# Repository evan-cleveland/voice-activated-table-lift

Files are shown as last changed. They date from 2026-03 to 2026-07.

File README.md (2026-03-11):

# Voice-Activated Table Lift

This project is a coffee table with a hidden lift mechanism that opens a compartment when the control electronics are triggered by a voice-password system.

At the moment, this repository contains the actuator-side ESP32 firmware and the mechanical / electronics design files. The actual speech-recognition or password-detection code is not in this repo yet, but will be in a matter of hours.

## [Current state of the project](https://youtube.com/shorts/O5TE6jEasQA?si=kaMg7j4xVM5jBZLz)
- I am successfully able to set any keywords as the open, close, and stop commands, and have the actuator respond as expected
- High latency from word detection model due to Pi Zero W running GUI and background tasks. This will be fixed with a headless OS.
- The lack of a proper footprint for parts has delayed PCB design.

## What is in the repo

- `code/esp/actuator`: PlatformIO project for an ESP32 that drives the lift motor.
- `cad/box.*`: enclosure / printable box files for part of the hardware.
- `cad/pcb`: KiCad project directory for the PCB.

## Firmware behavior

The ESP32 firmware is a small motor controller built with the Arduino framework.

- GPIO `26` (`S1`) and GPIO `27` (`S0`) are digital control inputs.
- GPIO `19` (`RPWM`) and GPIO `21` (`LPWM`) output PWM to the motor driver.
- GPIO `23` (`REN`) and GPIO `5` (`LEN`) are held high to enable the driver.
- PWM runs at `20 kHz` with `8-bit` resolution.
- Motor speed is currently fixed at full duty cycle (`255`).

Control logic:

- `S0 = HIGH`, `S1 = LOW`: drive in one direction.
- `S1 = HIGH`, `S0 = LOW`: drive in the opposite direction.
- `S0 = HIGH`, `S1 = HIGH`: stop.
- both low: stop.

This makes the firmware easy to pair with an external controller that decides when to open or close the hidden compartment.

## Hardware notes

The current firmware assumes:

- an ESP32 development board,
- a motor driver that accepts separate right/left PWM inputs plus enable pins,
- a linear actuator or DC motor for the lift mechanism,
- two logic-level control signals from whatever handles the voice trigger.

Because the KiCad schematic in `cad/pcb` is still mostly empty, the exact wiring is best taken from the pin definitions in `code/esp/actuator/src/main.cpp`.

## Building and flashing

Requirements:

- [PlatformIO](https://platformio.org/)
- an ESP32 board supported by the `esp32dev` PlatformIO target

Build:

```bash
cd code/esp/actuator
pio run
```

Flash:

```bash
cd code/esp/actuator
pio run --target upload
```

Optional serial monitor:

```bash
cd code/esp/actuator
pio device monitor --baud 115200
```

## Project structure

```text
.
|-- cad/
|   |-- box.3mf
|   |-- box.SLDPRT
|   |-- box.STL
|   `-- pcb/
`-- code/
    `-- esp/
        `-- actuator/
            |-- platformio.ini
            `-- src/main.cpp
```

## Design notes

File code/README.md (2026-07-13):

# Voice-Activated Table Lift

This repository contains the two runtime pieces for a voice-controlled lift table:

- `pi/`: Raspberry Pi speech-detection bridge using PocketSphinx and GPIO output pins.
- `esp/actuator/`: ESP32 firmware that reads two control lines and drives the actuator motor.

The current design is GPIO-based end to end. The Pi listens for keywords, maps them to command bits, and drives two output pins. The ESP32 reads those bits and selects motor direction or stop.

## Architecture

Command mapping:

- `EXTEND` -> `01`
- `RETRACT` -> `10`
- `STOP` -> `11`
- idle / no command -> `00`

Current pin usage:

- Raspberry Pi voice-command outputs: BCM `17` and `27`
- Raspberry Pi I2S mic input bus: BCM `18`, `19`, and `20`
- ESP32 inputs: GPIO `26` and `27`
- ESP32 contract limit switch input: GPIO `25` with `INPUT_PULLUP`
- ESP32 motor driver pins:
  - `RPWM = 19`
  - `LPWM = 21`
  - `REN = 23`
  - `LEN = 5`

## Repo Layout

```text
code/
|- pi/
|  |- voice_bridge.py
|  |- voice_config.json
|  |- requirements.txt
|  |- requirements-user.txt
|  |- apt-manual.txt
|  `- keywords.list
`- esp/
   `- actuator/
      |- platformio.ini
      |- src/main.cpp
      |- include/
      |- lib/
      `- test/
```

## Typical Flow

1. Flash the ESP32 firmware from `esp/actuator/`.
2. Wire the Pi GPIO outputs to the ESP32 command inputs and connect grounds.
3. Wire the I2S microphone to the Pi I2S pins and enable the matching sound-card overlay on the Pi.
4. Install PocketSphinx and the Pi-side Python dependencies.
5. Adjust `pi/voice_config.json` if you want different phrases or thresholds.
6. Run `voice_bridge.py` on the Pi.

## Notes

- The ESP32 retract path is interlocked by a normally-open limit switch that pulls GPIO `25` to ground when depressed.
- `voice_config.json` still includes `serial_port` and `baud_rate`, but the current script does not use serial.
- `pi/requirements.txt` appears to be a full environment freeze, not a minimal project dependency list.
- The generated keyword file is written to `pi/keywords.list` each time the bridge starts.

## Subproject Docs

- [Pi runtime](C:/Users/Evan/documents/cs/projects/voice-activated-table-lift/code/pi/README.md)
- [ESP32 actuator firmware](C:/Users/Evan/documents/cs/projects/voice-activated-table-lift/code/esp/actuator/README.md)

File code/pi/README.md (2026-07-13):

# Raspberry Pi Voice Bridge

This directory contains the speech-recognition process that listens for wake phrases and drives two GPIO outputs that represent actuator commands.

## Files

- `voice_bridge.py`: main runtime process
- `voice_config.json`: keyword list, PocketSphinx binary name, and cooldown settings
- `keywords.list`: generated PocketSphinx keyword file
- `requirements.txt`: current full pip freeze from the Pi environment
- `requirements-user.txt`: reserved for user-managed pip packages
- `apt-manual.txt`: manually installed apt packages from the target Pi

## Runtime Behavior

`voice_bridge.py` does the following:

1. Loads `voice_config.json`.
2. Rebuilds `keywords.list` from the configured phrases and thresholds.
3. Starts `pocketsphinx_continuous` with microphone input.
4. Maps recognized phrases to commands.
5. Drives GPIO outputs:
   - BCM `17`
   - BCM `27`
6. Applies a per-command cooldown.
7. Sends `STOP` on shutdown.

Configured commands in the checked-in config:

- `open` -> `EXTEND`
- `close` -> `RETRACT`
- `stop` -> `STOP`

Bit encoding used by the script:

- `EXTEND` -> `01`
- `RETRACT` -> `10`
- `STOP` -> `11`
- `NULL` -> `00`

## Setup

The code assumes a Raspberry Pi environment with:

- Python 3
- `gpiozero`
- PocketSphinx CLI available as `pocketsphinx_continuous`
- ALSA diagnostic tools such as `arecord` and `aplay` from `alsa-utils`
- microphone input working on the device

The checked-in `apt-manual.txt` shows PocketSphinx and the main Pi GPIO/audio packages that were installed on the target system.

Minimal run steps:

```powershell
cd pi
python voice_bridge.py
```

If you use a virtual environment, install the packages you actually need rather than blindly applying the full frozen `requirements.txt`.

## Run On Boot

The repo includes a `systemd` unit at `pi/voice-bridge.service` plus install
and disable helper scripts.

From the Pi:

```bash
cd /home/pi/voice-activated-table-lift/code/pi
chmod +x install-voice-bridge-service.sh disable-voice-bridge-service.sh
./install-voice-bridge-service.sh
```

The install script copies the service into `/etc/systemd/system/`, rewrites it
to use the current checkout path and current user, adds that user to the `audio`
group if needed, enables the service, and restarts it.

Check status and logs with:

```bash
sudo systemctl status voice-bridge.service
journalctl -u voice-bridge.service -f
```

If the install script adds your user to the `audio` group, reboot before relying
on boot-time audio access:

```bash
sudo reboot
```

Disable boot startup with:

```bash
cd /home/pi/voice-activated-table-lift/code/pi
./disable-voice-bridge-service.sh
```

## Configuration

`voice_config.json` currently contains:

- `cooldown_seconds`: minimum time between repeated sends of the same command
- `allow_repeat_stop`: whether `STOP` bypasses cooldown
- `pocketsphinx_binary`: executable to launch
- `audio_backend`: `pocketsphinx_mic` for direct PocketSphinx capture or
  `arecord_pipe` to pipe ALSA audio into PocketSphinx
- `audio_device`: optional PortAudio/ALSA capture device passed as `-adcdev`
- `audio_rate`: capture sample rate used by `arecord_pipe`
- `audio_channels`: capture channel count used by `arecord_pipe`
- `audio_format`: capture sample format used by `arecord_pipe`
- `audio_buffer_time_us`: ALSA capture buffer size used by `arecord_pipe`
- `keywords_file`: output file for generated keywords
- `keywords`: list of phrase mappings

The file also contains `serial_port` and `baud_rate`, but the present implementation does not use serial I/O.

Example:

```json
{
  "cooldown_seconds": 1.5,
  "allow_repeat_stop": true,
  "pocketsphinx_binary": "pocketsphinx_continuous",
  "audio_backend": "arecord_pipe",
  "audio_device": "plughw:0,0",
  "audio_rate": 16000,
  "audio_channels": 1,
  "audio_format": "S16_LE",
  "audio_buffer_time_us": 500000,
  "keywords_file": "keywords.list",
  "keywords": [
    { "phrase": "open", "threshold": "1e-20", "command": "EXTEND" },
    { "phrase": "close", "threshold": "1e-20", "command": "RETRACT" },
    { "phrase": "stop", "threshold": "1e-20", "command": "STOP" }
  ]
}
```

## Wiring Assumptions

The Pi uses two separate sets of GPIO wiring:

1. I2S microphone input into the Pi.
2. Digital command outputs from the Pi to the ESP32.

### I2S Microphone Wiring

For the Adafruit I2S MEMS Microphone Breakout - SPH0645LM4H used by this
project, wire the microphone signals to the Pi's I2S/PCM pins:

| Pi signal | Pi BCM GPIO | Physical header pin | I2S mic label commonly seen |
| --- | ---: | ---: | --- |
| PCM clock | `18` | `12` | `BCLK`, `SCK`, or `SCLK` |
| PCM frame sync | `19` | `35` | `LRCLK`, `WS`, `FS`, or `LRC` |
| PCM data in | `20` | `38` | `DOUT`, `SD`, `SDOUT`, or `DATA` |
| 3.3 V power | n/a | `1` or `17` | `3V` |
| Ground | n/a | any Pi ground pin | `GND` |
| Channel select | n/a | any Pi ground pin for mono | `SEL` |

If using two I2S mics on the same bus, both mics share `BCLK`, `LRCLK/WS`,
`DOUT/SD`, `3.3 V`, and `GND`. Set one mic's `SEL`, `L/R`, or `LR` pin low
and the other high so they occupy opposite left/right slots. On many breakout
boards that means one `SEL/LR` pin goes to `GND` and the other goes to `3.3 V`.

GPIO `17` and GPIO `27` are not microphone pins in this project.

### ESP32 Command Wiring

The script drives these Pi outputs:

- BCM `17` as the first command bit
- BCM `27` as the second command bit

The ESP32 firmware currently expects the incoming command bits on:

- GPIO `26` as `S1`
- GPIO `27` as `S0`

Use a shared ground between the Pi and ESP32, and verify voltage compatibility before direct GPIO connection.

## Audio Device Troubleshooting

By default, `voice_bridge.py` uses `arecord_pipe`, which captures from ALSA and
pipes raw audio into PocketSphinx:

```bash
arecord -D plughw:0,0 -c 1 -r 16000 -f S16_LE -t raw --buffer-time 500000 |
  pocketsphinx_continuous -infile /dev/stdin -kws keywords.list -samprate 16000
```

This avoids PocketSphinx's PortAudio capture path, which can fail on Ubuntu
Server with `Error opening audio device (null) for capture: Connection refused`.

If `audio_backend` is set to `pocketsphinx_mic`, `voice_bridge.py` starts
PocketSphinx with:

```bash
pocketsphinx_continuous -inmic yes -kws keywords.list
```

In that mode, if `audio_device` is set in `voice_config.json`, the bridge passes
`-adcdev <audio_device>` to PocketSphinx.

The error shown by PocketSphinx as `Failed to open audio device` means
PocketSphinx and its language model started, but PortAudio/ALSA could not open
a usable capture device. On Ubuntu Server this usually means the I2S sound-card
overlay is not enabled, ALSA does not have a default capture device, or the
runtime user does not have permission to use the audio device.

Check whether Linux sees any capture devices:

```bash
sudo apt update
sudo apt install alsa-utils python3-pyaudio
arecord -l
arecord -L
```

On newer Ubuntu releases, `pip install pyaudio` in the system Python may fail
with an "externally managed environment" error. That is expected; install the
system package with `sudo apt install python3-pyaudio` instead, or use a virtual
environment if you need pip-managed packages.

If no capture card appears, enable the sound-card overlay for the Adafruit
SPH0645LM4H breakout. On Ubuntu Server for Raspberry Pi this is normally edited
in `/boot/firmware/config.txt`; on Raspberry Pi OS it is usually
`/boot/config.txt`. Add:

```ini
dtoverlay=googlevoicehat-soundcard
```

After changing boot config, reboot and check `arecord -l` again.

Once a capture device exists, test recording before starting the bridge:

```bash
arecord -D plughw:1 -c1 -r 48000 -f S32_LE -t wav -V mono -v /tmp/mic-test.wav
aplay /tmp/mic-test.wav
```

For the bridge's default pipe path, test the same rate and format it uses:

```bash
arecord -D plughw:0,0 -c1 -r 16000 -f S16_LE -t raw --buffer-time 500000 |
  pocketsphinx_continuous -infile /dev/stdin -kws keywords.list -samprate 16000
```

`arecord` overrun messages mean the capture buffer filled before the downstream
process consumed all samples. Occasional overruns are not fatal if recognition
works. If they are frequent, increase `audio_buffer_time_us` in
`voice_config.json`, for example to `1000000`, or test whether `audio_rate`
`48000` is more stable with the sound card.

If `arecord -l` shows the mic but `pocketsphinx_continuous -inmic yes` still
fails, set the ALSA default capture device in `~/.asoundrc` or `/etc/asound.conf`
so PortAudio has a `default` input device to open, or set `audio_device` in
`voice_config.json` to an explicit ALSA device such as `plughw:1,0` after
confirming the card and device numbers with `arecord -l`.

Also verify that the service user is in the `audio` group:

```bash
groups
sudo usermod -aG audio "$USER"
```

Log out and back in after changing group membership.

## Limitations

- No debounce or confidence filtering beyond PocketSphinx keyword thresholds and cooldown.
- No unit tests are present for the Pi runtime.

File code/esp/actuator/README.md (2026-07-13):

# ESP32 Actuator Firmware

This PlatformIO project reads a 2-bit command from external GPIO lines and drives a motor controller for the table lift actuator.

## Project

- Platform: `espressif32`
- Board: `esp32dev`
- Framework: `arduino`
- Monitor speed: `115200`

## Source Layout

- `src/main.cpp`: main firmware
- `include/`: shared headers, currently unused
- `lib/`: local libraries, currently unused
- `test/`: PlatformIO test directory, currently unused

## Command Inputs

The firmware reads two input pins with pulldowns enabled:

- `S1 = 26`
- `S0 = 27`
- `CONTRACT_LIMIT_SWITCH = 25`

Command behavior:

- `11` -> stop motor
- `01` -> drive `RPWM`
- `10` -> drive `LPWM` unless the contract limit switch is active
- `00` -> stop motor

This matches the command encoding produced by the Pi bridge.

## Contract Limit Switch

The contract limit switch input uses the ESP32 internal pull-up:

- wiring mode: normally open
- inactive state: open circuit, input reads `HIGH`
- active state: switch depressed, input is connected to ground and reads `LOW`

When the switch is active, the firmware stops the motor and ignores further retract commands until the switch is released.

As an additional safety check, the firmware also stops if the switch transitions from released to depressed while the `01` command is active. Under normal operation that should not happen during extension; it usually indicates the motor controller direction wiring is reversed.

## Motor Driver Pins

- `RPWM = 19`
- `LPWM = 21`
- `REN = 23`
- `LEN = 5`

PWM configuration:

- frequency: `20000`
- resolution: `8`
- channels: `0` and `1`
- speed value: `255`

## Build And Flash

Typical PlatformIO commands:

```powershell
cd esp\actuator
pio run
pio run -t upload
pio device monitor -b 115200
```

You can also build and upload through the PlatformIO VS Code extension if that is how you are working on the ESP32 side.

## Wiring Notes

- The two command input lines should come from the Raspberry Pi GPIO outputs documented in the Pi README.
- Wire the contract limit switch between GPIO `25` and ground if you use the default pin assignment in `src/main.cpp`.
- Grounds must be shared between the control side and the ESP32.
- Confirm that the electrical interface between the Pi GPIO and ESP32 input pins is safe for your board configuration.

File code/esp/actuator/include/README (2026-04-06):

Project header directory for the ESP32 actuator firmware.

Use this folder for shared declarations if the firmware grows beyond a single
`src/main.cpp` file.

Current status:

- No custom headers are required yet.
- Input pins, PWM channels, and motor helpers are defined directly in
  `src/main.cpp`.

If the project is split into modules later, place public headers here and keep
implementation files in `src/` or `lib/`.

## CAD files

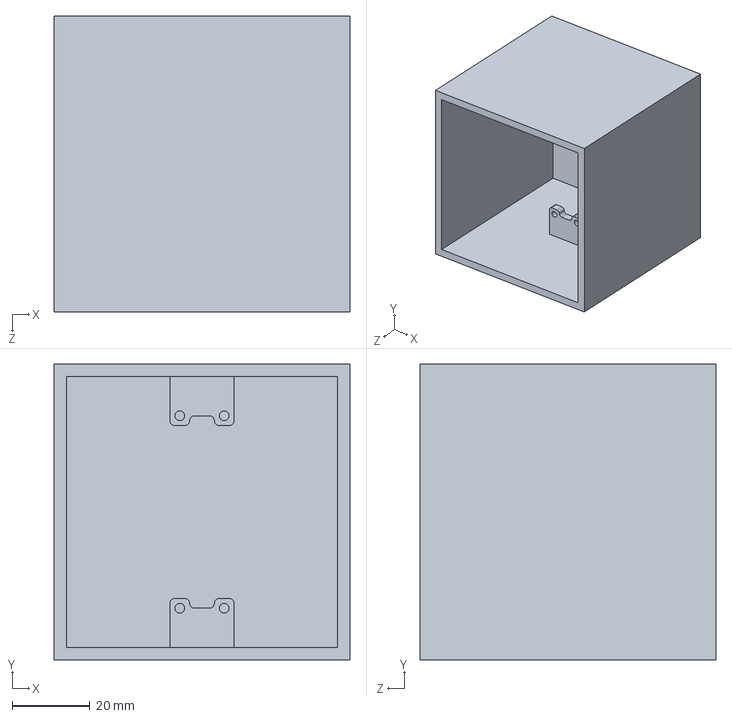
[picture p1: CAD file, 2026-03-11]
cad/box.SLDPRT
76.2 x 76.2 x 76.2 mm

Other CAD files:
cad/box.3mf
cad/box.STL

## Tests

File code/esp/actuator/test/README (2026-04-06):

PlatformIO test directory for the ESP32 actuator firmware.

Current status:

- No automated tests are checked in.

Useful future targets for tests:

- command-bit decoding
- stop behavior for `00` and `11`
- motor direction selection for `01` and `10`
- any future safety interlocks or limit-switch logic

When tests are added, place them here for use with `pio test`.

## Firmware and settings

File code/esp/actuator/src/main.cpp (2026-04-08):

#include <Arduino.h>

static const int RPWM = 19;
static const int LPWM = 21;
static const int REN  = 23;
static const int LEN  = 5;

static const int PWM_FREQ = 20000;
static const int PWM_RES  = 8;
static const int PWM_CH_R = 0;
static const int PWM_CH_L = 1;

static const int S1 = 26;
static const int S0 = 27;
static const int CONTRACT_LIMIT_SWITCH = 25;

static const int MOTOR_SPEED = 255;
//String buf;

void motorStop() {
  ledcWrite(PWM_CH_R, 0);
  ledcWrite(PWM_CH_L, 0);
  //Serial.println("MOTOR STOP");
}

void motorRPWM() {
  ledcWrite(PWM_CH_R, MOTOR_SPEED);
  ledcWrite(PWM_CH_L, 0);
  //Serial.println("MOTOR RPWM");
}

void motorLPWM() {
  ledcWrite(PWM_CH_R, 0);
  ledcWrite(PWM_CH_L, MOTOR_SPEED);
  //Serial.println("MOTOR LPWM");
}

bool contractLimitReached() {
  return digitalRead(CONTRACT_LIMIT_SWITCH) == LOW;
}

void setup() {
  pinMode(S1, INPUT_PULLDOWN);
  pinMode(S0, INPUT_PULLDOWN);
  pinMode(CONTRACT_LIMIT_SWITCH, INPUT_PULLUP);

  pinMode(REN, OUTPUT);
  pinMode(LEN, OUTPUT);
  digitalWrite(REN, HIGH);
  digitalWrite(LEN, HIGH);

  ledcSetup(PWM_CH_R, PWM_FREQ, PWM_RES);
  ledcSetup(PWM_CH_L, PWM_FREQ, PWM_RES);
  ledcAttachPin(RPWM, PWM_CH_R);
  ledcAttachPin(LPWM, PWM_CH_L);

  motorStop();
  //Serial.println("READY");
}

void loop() {
  if (digitalRead(S1) == HIGH && digitalRead(S0) == HIGH) {
    motorStop();
  } else
  if (digitalRead(S0) == HIGH) {
    motorRPWM();
  } else if (digitalRead(S1) == HIGH) {
    if (contractLimitReached()) {
      motorStop();
    } else {
      motorLPWM();
    }
  } else {
    motorStop();
  }
}

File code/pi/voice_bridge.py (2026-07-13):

#!/usr/bin/env python3
import json
import os
import subprocess
import sys
import time
from pathlib import Path
from gpiozero import DigitalOutputDevice as DO

#try:
#    import serial
#except ImportError:
#    print("Missing pyserial. Install with: sudo apt install python3-serial", file=sys.stderr)
#    sys.exit(1)


CONFIG_PATH = Path("voice_config.json")

command_codes = {'EXTEND': '01', 'RETRACT': '10', 'STOP': '11', 'NULL': '00'}

def load_config(path: Path):
    with open(path, "r", encoding="utf-8") as f:
        cfg = json.load(f)

    required_top = [
#        "serial_port",
#        "baud_rate",
        "cooldown_seconds",
        "allow_repeat_stop",
        "pocketsphinx_binary",
        "keywords_file",
        "keywords",
    ]
    for key in required_top:
        if key not in cfg:
            raise ValueError(f"Missing config key: {key}")

    if not isinstance(cfg["keywords"], list) or not cfg["keywords"]:
        raise ValueError("Config 'keywords' must be a non-empty list")

    for i, item in enumerate(cfg["keywords"]):
        for key in ("phrase", "threshold", "command"):
            if key not in item:
                raise ValueError(f"Keyword entry {i} missing key: {key}")

    return cfg


def build_keyword_file(cfg):
    kw_path = Path(cfg["keywords_file"])
    lines = []
    phrase_to_command = {}

    for item in cfg["keywords"]:
        phrase = item["phrase"].strip().lower()
        threshold = str(item["threshold"]).strip()
        command = item["command"].strip().upper()

        if not phrase:
            continue

        lines.append(f"{phrase} /{threshold}/")
        phrase_to_command[phrase] = command

    kw_path.write_text("\n".join(lines) + "\n", encoding="utf-8")
    return kw_path, phrase_to_command


#def open_serial(port, baud_rate):
 #   while True:
 #       try:
 #           ser = serial.Serial(port, baud_rate, timeout=1)
 #           print(f"[SERIAL] Connected to {port} @ {baud_rate}")
 #           time.sleep(2.0)  # allow ESP32 reset if using USB serial
 #           return ser
 #       except Exception as e:
 #           print(f"[SERIAL] Failed to open {port}: {e}")
 #           print("[SERIAL] Retrying in 2 seconds...")
 #           time.sleep(2)


def send_command(o1, o0, command):
 #   msg = command.strip().upper() + "\n"
 #   ser.write(msg.encode("utf-8"))
#    ser.flush()
#    print(f"[SEND] {msg.strip()}")
    code = str(command_codes[command])
    if code[0]=='1':
        o1.on()
    else:
        o1.off()

    if code[1]=='1':
        o0.on()
    else:
        o0.off()

def start_pocketsphinx(binary, kw_path, audio_device=None):
    cmd = [binary, "-inmic", "yes", "-kws", str(kw_path)]
    if audio_device:
        cmd.extend(["-adcdev", str(audio_device)])
    print("[PS] Starting:", " ".join(cmd))
    return subprocess.Popen(
        cmd,
        stdout=subprocess.PIPE,
        stderr=subprocess.STDOUT,
        text=True,
        bufsize=1,
        universal_newlines=True,
    )


def start_arecord_pocketsphinx(cfg, kw_path):
    audio_device = cfg.get("audio_device") or "plughw:0,0"
    rate = str(cfg.get("audio_rate", 16000))
    channels = str(cfg.get("audio_channels", 1))
    fmt = str(cfg.get("audio_format", "S16_LE"))
    buffer_time = str(cfg.get("audio_buffer_time_us", 500000))

    arecord_cmd = [
        "arecord",
        "-D", str(audio_device),
        "-c", channels,
        "-r", rate,
        "-f", fmt,
        "-t", "raw",
        "--buffer-time", buffer_time,
    ]
    ps_cmd = [
        cfg["pocketsphinx_binary"],
        "-infile", "/dev/stdin",
        "-kws", str(kw_path),
        "-samprate", rate,
    ]

    print("[AUDIO] Starting:", " ".join(arecord_cmd))
    print("[PS] Starting:", " ".join(ps_cmd))

    arecord = subprocess.Popen(
        arecord_cmd,
        stdout=subprocess.PIPE,
        stderr=subprocess.DEVNULL,
    )
    ps = subprocess.Popen(
        ps_cmd,
        stdin=arecord.stdout,
        stdout=subprocess.PIPE,
        stderr=subprocess.STDOUT,
        text=True,
        bufsize=1,
        universal_newlines=True,
    )
    if arecord.stdout is not None:
        arecord.stdout.close()
    return ps, arecord


def main():
    cfg = load_config(CONFIG_PATH)
    kw_path, phrase_to_command = build_keyword_file(cfg)

    S1 = DO(17)
    S0 = DO(27)
    #ser = open_serial(cfg["serial_port"], cfg["baud_rate"])
    arecord = None
    if cfg.get("audio_backend") == "arecord_pipe":
        ps, arecord = start_arecord_pocketsphinx(cfg, kw_path)
    else:
        ps = start_pocketsphinx(cfg["pocketsphinx_binary"], kw_path, cfg.get("audio_device"))

    last_sent_time = {}
    cooldown = float(cfg["cooldown_seconds"])
    allow_repeat_stop = bool(cfg["allow_repeat_stop"])

    try:
        assert ps.stdout is not None

        for raw_line in ps.stdout:
            line = raw_line.strip()
            if not line:
                continue

            print(f"[PS] {line}")

            spoken = line.lower().strip()

            if spoken in phrase_to_command:
                command = phrase_to_command[spoken]
                now = time.time()
                last_time = last_sent_time.get(command, 0)

                if command == "STOP" and allow_repeat_stop:
                    send_command(S1, S0, command)
                    last_sent_time[command] = now
                    continue

                if now - last_time >= cooldown:
                    send_command(S1, S0, command)
                    last_sent_time[command] = now
                else:
                    print(f"[SKIP] Cooldown active for {command}")

    except KeyboardInterrupt:
        print("\n[EXIT] Stopping...")
    finally:
        try:
            send_command(S1, S0, "STOP")
        except Exception:
            pass

        try:
            if ps.poll() is None:
                ps.terminate()
                time.sleep(1)
                if ps.poll() is None:
                    ps.kill()
        except Exception:
            pass

        try:
            if arecord is not None and arecord.poll() is None:
                arecord.terminate()
                time.sleep(1)
                if arecord.poll() is None:
                    arecord.kill()
        except Exception:
            pass

#        try:
#            ser.close()
        except Exception:
            pass


if __name__ == "__main__":
    main()

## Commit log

2026-03-11 Initial commit of working system
    [box.3mf, box.SLDPRT, box.STL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]
2026-03-11 Revise README with project updates and video link
    Updated the README to reflect the upcoming addition of speech-recognition code and included a link to the current state of the project.
2026-03-11 Revise project status and repository contents
    Updated project status and added details about current issues.
2026-03-11 Remove limitations and next steps from README
    Removed current limitations and next steps sections from README.
2026-04-08 limit switch + running on boot
